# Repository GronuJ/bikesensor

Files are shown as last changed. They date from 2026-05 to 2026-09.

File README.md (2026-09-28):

# bikesensor 🚲📡

**A standalone, low-cost, pure IoT hardware and software mapping pipeline for geo-tagged bike vibration and road-quality analysis.**

`bikesensor` turns an ESP32-C3 SuperMini, an MPU-6050 IMU, a NEO-6M GPS, and an SPI MicroSD card module into a standalone, battery-powered mapping box. 

When you ride, the device autonomously records high-frequency (200 Hz) vertical accelerometer vibrations and sparse (1 Hz) GPS coordinate ticks into unified local CSV log files on the SD card. When you return home, the device connects to your home Wi-Fi and uploads all offline ride CSVs over HTTPS to [kiel.earth](https://kiel.earth), where the rides are stored, processed and mapped. That website lives in its own repository; this one holds the firmware, the carrier PCB and the enclosure.

---

## ⚠️ Project status

* **The custom PCB has been ordered** (38.74 × 114.47 mm, `production/bikesensor.zip`) but not assembled. Its ESP32 headers were routed against the wrong SuperMini pinout, so every signal lands on a different GPIO than the hand-wired prototype used. The default firmware build is remapped to match the board; the battery sense needs one bodge wire during assembly, and the module must be mounted face down. Details in `custom_pcb/PIN_VERIFICATION.md`.
* **The hardware has never produced a real ride.** Every figure produced so far comes from synthetic signals.

---

## 📸 Hardware Showcase

Below is the completed physical system mounted on a custom 3D-printed handlebar enclosure and its 3D modeling design:

| Physical System | 3D Printed Enclosure Design |
| :---: | :---: |
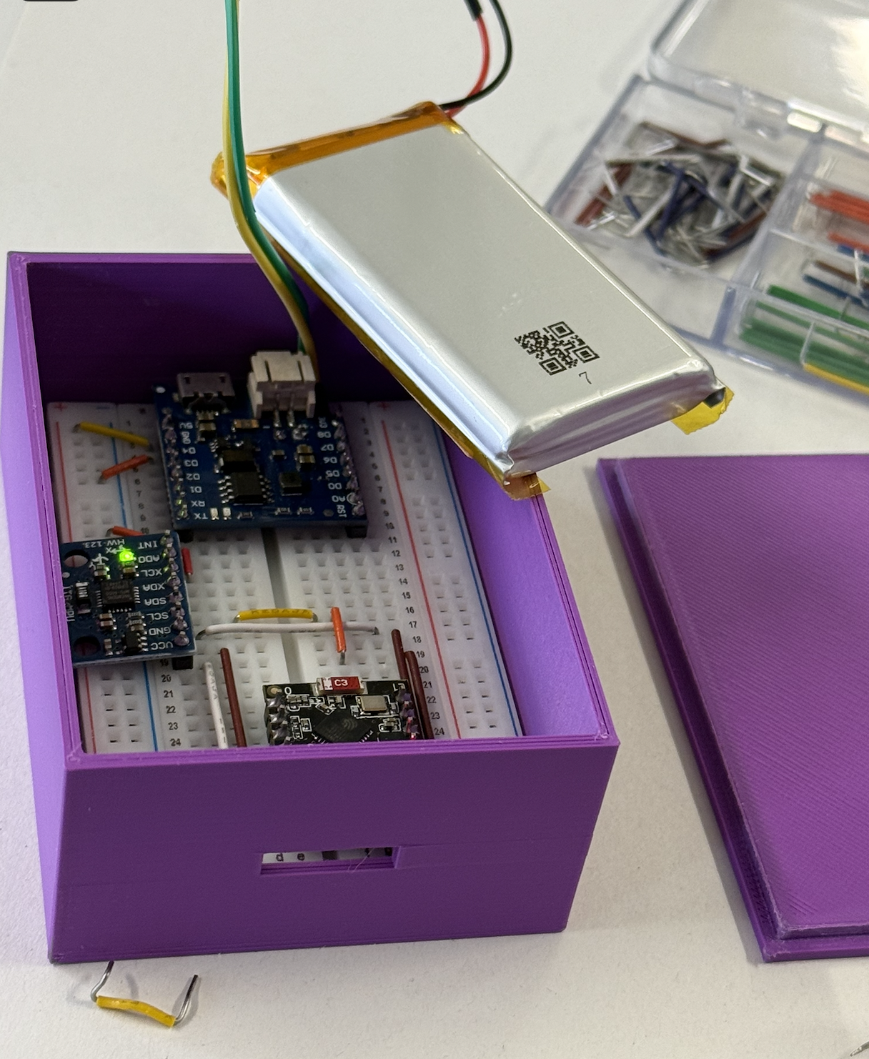
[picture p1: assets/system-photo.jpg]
Bikesensor Physical System
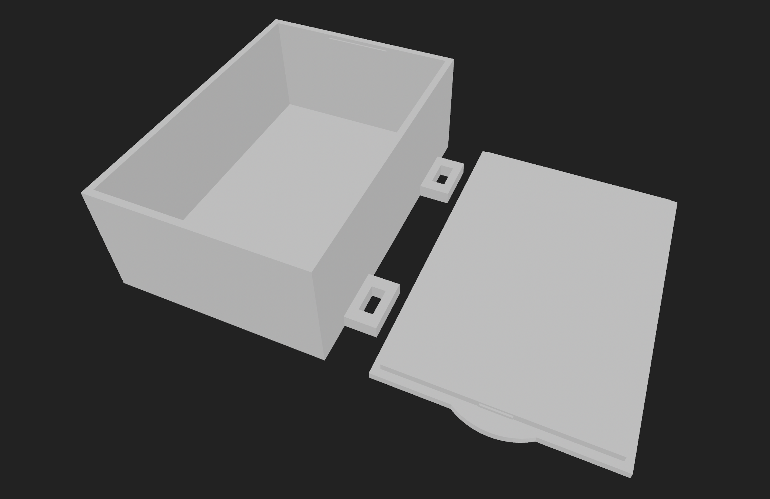
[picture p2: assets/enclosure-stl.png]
3D Printed Enclosure STL
|  |  |

---

## 1. System Architecture

```mermaid
flowchart TD
    subgraph Riding [1. Outdoor Bike Ride]
        ESP[ESP32-C3 SuperMini]
        IMU[MPU-6050 Accelerometer 200Hz] --> ESP
        GPS[NEO-6M GPS Module 1Hz] --> ESP
        ESP -->|Log unified CSV| SD[(SPI MicroSD Card)]
    end

    subgraph Home [2. Arrival Home & Wi-Fi Sync]
        ESP_H[ESP32-C3 Home Mode] -->|Connects to home Wi-Fi| Router((Home Router))
        SD -->|Stream CSVs over HTTPS POST| ESP_H
        ESP_H -->|/api/bike/ingest| Site[kiel.earth]
        Site -->|2xx: file is stored| ESP_H
        ESP_H -->|Delete uploaded file| SD
    end
```

---

## 2. Hardware Wiring & Custom PCB Carrier

The hardware operates on **3.3V logic** for standard communication and SD logging, driven by a Wemos D1 Mini TP5400 Battery Shield. 

Here is the physical wiring diagram for our custom carrier board:

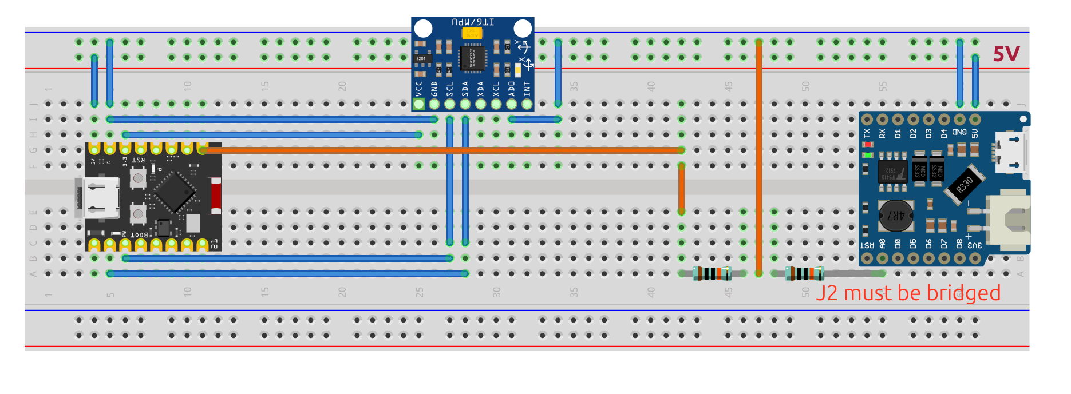
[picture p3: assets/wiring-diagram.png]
Bikesensor Electrical Wiring Diagram


### Schematic

R3 (10 kΩ) pulls `SPI_CS` to `+3V3`, keeping the card deselected while the ESP32 boots. The schematic's ESP32 connectors are generic sockets, so it does not show which GPIO each net reaches; the table below does.

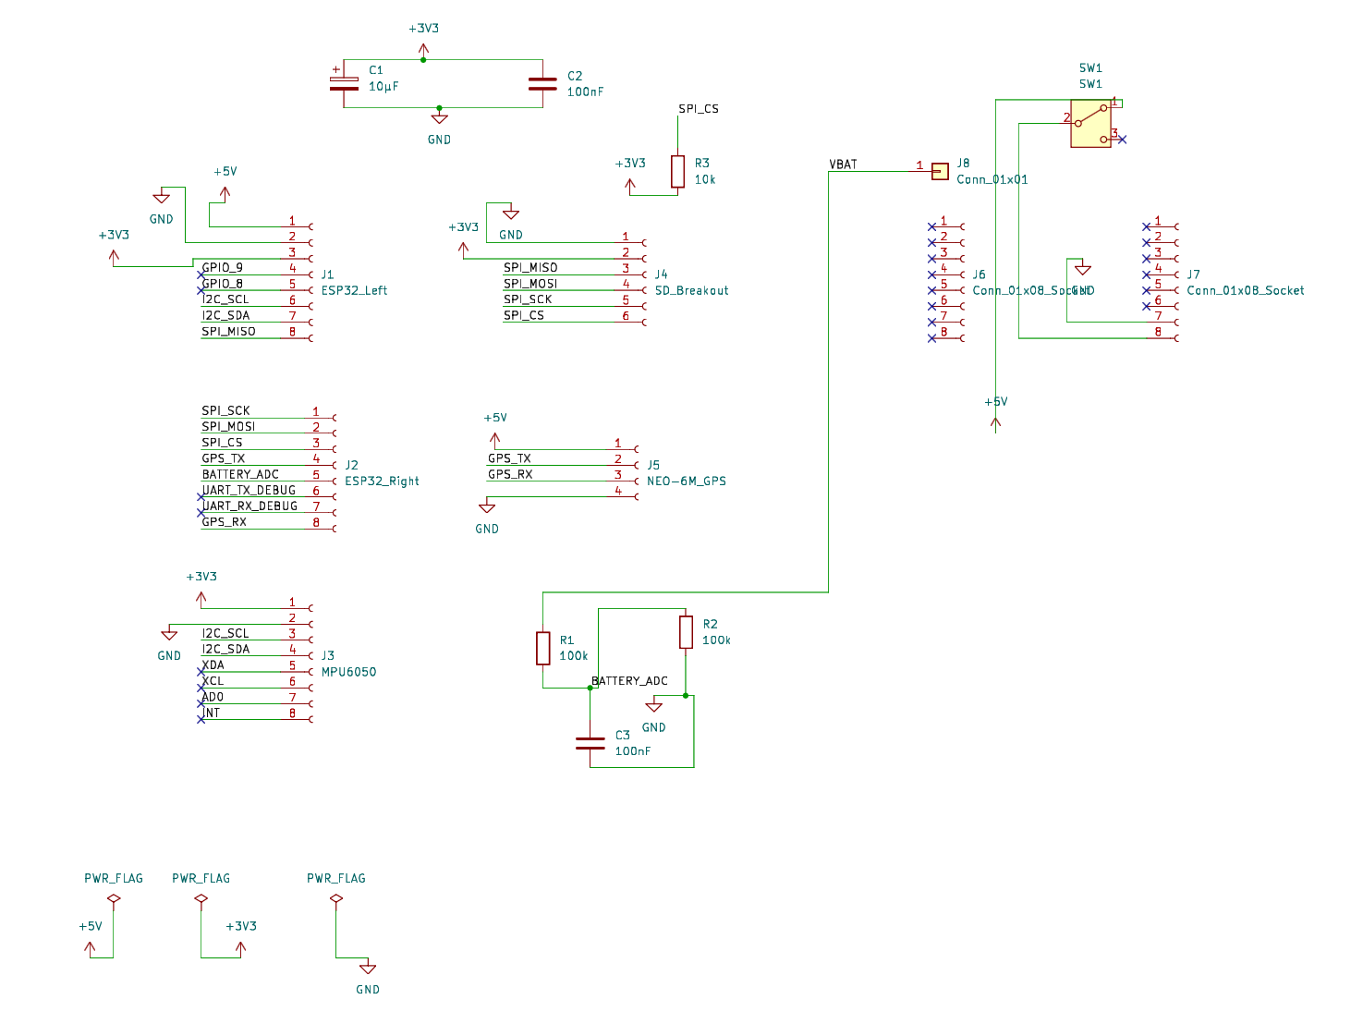
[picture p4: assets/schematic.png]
Schematic


### Board

The carrier is 38.74 × 114.47 mm, 2-layer, all through-hole. Every connected pin carries a silkscreen signal name — `GTX`/`GRX` are the GPS UART, `DTX`/`DRX` the debug UART, and `ADC` the battery divider.

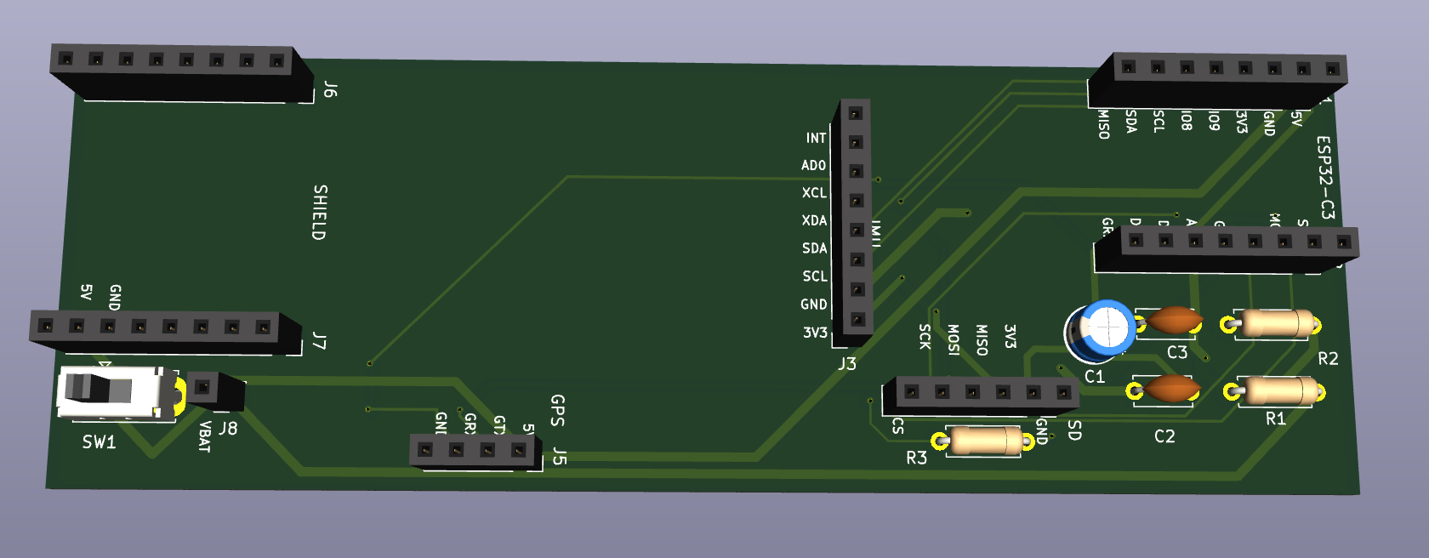
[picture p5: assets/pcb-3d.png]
PCB 3D render


### Pin Map Table:

GPIOs are for the carrier PCB (default firmware build). The hand-wired prototype used different ones — `pio run -d firmware -e handwired`.

| Peripheral | Connection | Pin | Notes |
| :--- | :--- | :--- | :--- |
| **MPU-6050 (I2C)** | SDA | **GPIO 1** | J1.7, shared I2C bus |
| | SCL | **GPIO 2** | J1.6. Strapping pin, held high by the GY-521's pull-ups |
| | VCC / GND | **3V3 / GND** | Powered by system 3.3V rail |
| **MicroSD (SPI)** | CS | **GPIO 7** | J2.3, R3 pull-up |
| | MOSI | **GPIO 6** | J2.2 |
| | SCK | **GPIO 5** | J2.1 |
| | MISO | **GPIO 0** | J1.8 |
| | VCC / GND | **3V3 / GND** | Powered by system 3.3V rail |
| **NEO-6M (UART1)** | TX / RX | **GPIO 8 / GPIO 21** | J2.4 / J2.8. Firmware detects which one the GPS transmits on |
| | VCC / GND | **5V / GND** | Powered by 5V boost output |
| **Wemos Battery Shield** | 5V Out | **J7 Pin 8** | Boosted 5.0V output |
| | GND | **J7 Pin 7** | System Ground |
| **SPDT Slide Switch (SW1)** | In / Out | **In Series** | Connected between `J7 Pin 8` (5V out) and `5V` net (ESP32 5V pin). Completely cuts off system power while preserving USB charging. |
| **Voltage Divider (R1, R2, C3)** | Junction | **GPIO 3** | Routed to J2.5 = GPIO 9, which has no ADC; reaches GPIO 3 only via the bodge wire in `PIN_VERIFICATION.md`. **R1 (100kΩ)** and **R2 (100kΩ)** divide raw battery voltage in half (`4.2V -> 2.1V`) for safe ADC reading. **C3 (100nF)** in parallel with R2 filters noise. |
| **Decoupling Caps (C1, C2)** | Parallel | **3V3 / GND** | **C1 (47µF radial; 10µF fits but is marginal)** and **C2 (100nF ceramic)** placed in parallel next to the MicroSD socket prevent write-cycle voltage sags. |

---

## 3. Firmwares (PlatformIO)

The firmware resides in `firmware/bikesensor/bikesensor.ino` and compiles out-of-the-box.

### Secure Credentials (Git-Ignored)
To protect your home Wi-Fi passwords from being committed to Git, create a file named `private_credentials.h` inside `firmware/bikesensor/`:
```cpp
#pragma once
#define WIFI_SSID "YourHomeSSID"
#define WIFI_PASS "YourHomePassword"
#define SERVER_HOST "kiel.earth"
#define SERVER_PORT 443
#define SERVER_UPLOAD_PATH "/api/bike/ingest"
#define DEVICE_TOKEN "your-device-token"   // sent as: Authorization: Bearer <token>
```
The firmware preprocessor will automatically detect and include this file during compile, keeping your passwords safe and isolated in your local workspace.

### Compilation Commands:
```bash
pio run -d firmware              # Build firmware binary
pio run -d firmware -t upload    # Flash to ESP32-C3 (Serial port is auto-detected)
pio device monitor -b 115200     # Real-time console debugger
```

---

## 4. Device-to-Server Interface

The logging box talks to the website over a single HTTPS endpoint.

### 4.1 CSV Log Data Format
When writing to the MicroSD card, the device registers data in a unified, comma-separated format:
```csv
millis,ax,ay,az,lat,lon,ele,speed_kmh,battery_pct,gps_time
```
*   `millis`: Relative milliseconds from ESP32 boot (used to align high-frequency vibration data).
*   `ax,ay,az`: Raw vertical/lateral/longitudinal accelerometer values (the ±4 g scale, `1/8192`, is applied on the website, not on the device).
*   `lat,lon,ele,speed_kmh`: GPS coordinate details.
*   `battery_pct`: Divided battery measurement (`0 - 100%`) read from `GPIO 3` on the carrier PCB (`GPIO 0` on the hand-wired prototype).
*   `gps_time`: GPS UTC timestamp (used as a clock reference).

### 4.2 Wireless Sync Protocol
When the ESP32-C3 boots in Wi-Fi sync mode upon returning home, it uploads every ride file on the SD card, one HTTPS request each:

*   **HTTP Method:** `POST`
*   **Request URL:** `https://kiel.earth/api/bike/ingest` (set by `SERVER_HOST` / `SERVER_UPLOAD_PATH`)
*   **Request Headers:** `Content-Type: text/csv`, `Authorization: Bearer <DEVICE_TOKEN>`, `X-Ride-Id: <filename without .csv>`
*   **Request Body:** the raw CSV file.

The device deletes a file from the SD card only after a 2xx response. On a timeout, TLS failure or any other status it keeps the file and retries on the next sync.

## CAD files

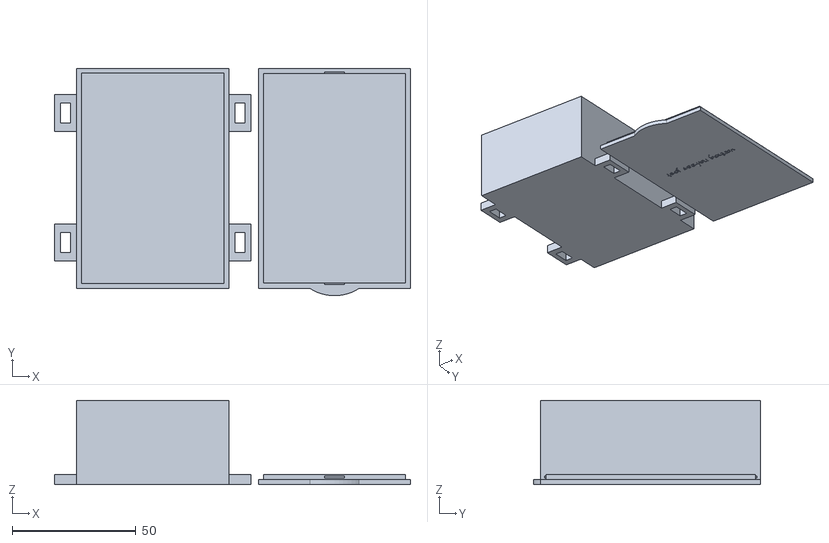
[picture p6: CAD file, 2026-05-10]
stl_files/box-3.stl
144.0 x 92.0 x 34.0

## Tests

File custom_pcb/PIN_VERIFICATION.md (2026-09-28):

# Pin verification sheet

Generated from `bikesensor_pcb/bikesensor_pcb.kicad_pcb` (the actual routed netlist), cross-referenced
against the real ESP32-C3 SuperMini pinout and the firmware constants in
`firmware/bikesensor/bikesensor.ino`.

**Why this file exists.** The schematic uses generic `Conn_01x0N_Socket` symbols — "ESP32_Left",
"MPU6050", "SD_Breakout" are only *Value* strings, not real parts with named pins. So the mapping
from header pin number to ESP32 GPIO exists nowhere the tools can check, and neither ERC nor DRC can
validate it. DRC passing clean means nothing here.

---

## Result (2026-09-22): J1/J2 were routed against the wrong pinout

The SuperMini's two rows, counted from the USB-C end, are:

```
row A:  5V   GND  3V3  IO4  IO3  IO2  IO1  IO0
row B:  IO5  IO6  IO7  IO8  IO9  IO10 IO20 IO21
```

Sources: the pad/pin tables in the [mrtnvgr/KiCad_ESP32-C3-SuperMini](https://github.com/mrtnvgr/KiCad_ESP32-C3-SuperMini)
footprint and symbol (pad 8 = 5V and pad 9 = IO5 share the same end, rows 15.24 mm apart), and the
[components101 pin table](https://components101.com/development-boards/esp32c3-mini-development-board-datasheet-pinout).
The same labels are printed on the module itself.

J1.1–J1.3 are `+5V, GND, +3V3`, so J1 is row A and J1.1 is the USB end. J2.1 sits directly across from
J1.1, so it is IO5. **This only works with the module face down** (see "Mount the module face down"
below): J1 is on the left of the carrier and J2 on the right, which is the mirror image of the module
seen from its component side. The board's `GPIO_9`/`GPIO_8` net names came from a pinout that
does not exist; the copper actually does this:

| Conn.pin | Net (silkscreen) | SuperMini pin | Hand-wired prototype used | Carrier firmware |
| --- | --- | --- | --- | --- |
| J1.1 | `+5V` | 5V | | |
| J1.2 | `GND` | GND | | |
| J1.3 | `+3V3` | 3V3 | | |
| J1.4 | `GPIO_9` (stub) | **IO4** | SPI SCK | free |
| J1.5 | `GPIO_8` (stub) | **IO3** | SPI MOSI | battery ADC, *after the bodge below* |
| J1.6 | `I2C_SCL` | **IO2** | SPI CS | I2C SCL |
| J1.7 | `I2C_SDA` | **IO1** | GPS (ESP TX) | I2C SDA |
| J1.8 | `SPI_MISO` | **IO0** | battery ADC | SPI MISO |
| J2.1 | `SPI_SCK` | **IO5** | SPI MISO | SPI SCK |
| J2.2 | `SPI_MOSI` | **IO6** | I2C SDA | SPI MOSI |
| J2.3 | `SPI_CS` | **IO7** | I2C SCL | SPI CS |
| J2.4 | `GPS_TX` | **IO8** (onboard LED) | LED | GPS UART, direction auto-detected |
| J2.5 | `BATTERY_ADC` | **IO9** (BOOT) | — | **none: IO9 has no ADC** |
| J2.6 | `UART_TX_DEBUG` | IO10 | GPS (ESP RX) | free |
| J2.7 | `UART_RX_DEBUG` | IO20 | | free |
| J2.8 | `GPS_RX` | IO21 | | GPS UART, direction auto-detected |

Not one signal lands where the original firmware expected it. The hand-wired prototype followed the
firmware, which is why it worked (the 2026-09-16 bench notes — divider on GPIO0, MISO on GPIO5, SDA
on GPIO6 — describe that hand wiring, not this PCB).

**What firmware absorbs.** The C3 routes SPI, I2C and UART through its GPIO matrix to any pin, so the
default firmware build (`pio run -d firmware`) now uses the "Carrier firmware" column. The original
map lives on as `pio run -d firmware -e handwired`. The GPS UART tries both carrier pins at boot and
uses whichever one carries NMEA, so the GPS breakout's header order (VCC-TX-RX-GND vs VCC-RX-TX-GND
both exist) does not matter.

**What firmware cannot absorb: the battery sense.** `BATTERY_ADC` lands on IO9, which has no ADC
channel, and IO9 is the BOOT strapping pin: it must read high at reset or the chip enters download
mode instead of running. With R1/R2 fitted, the divider (VBAT/2 through 50 kΩ) fights the ~45 kΩ
internal pull-up; that works out to about 2.5 V at a 3.3 V cell against a 2.48 V input-high threshold,
so a low battery could stop the logger booting.

### The one bodge (do it while assembling)

1. Before soldering J2, **clip off leg 5** of that 8-pin female header (or push its contact out). The
   module's IO9 then touches a contact that goes nowhere.
2. On the bottom side, solder a short wire from the **J2.5 pad** (still carrying `BATTERY_ADC` from
   R1/R2/C3) to the **J1.5 pad** (IO3, ADC1 channel 3; the `GPIO_8` stub has nothing else on it).

Result: battery sense on IO3, IO9 left to its internal pull-up and the BOOT button. The firmware's
carrier build already reads the battery on GPIO3.

If you would rather skip it: still clip leg 5, and leave R1 unfitted. The logger works;
`battery_pct` in the CSV is meaningless (IO3 floats).

### Mount the module face down

This is the standard assembly for this board revision, which is the one in use. J1/J2 are the
**mirror image** of the SuperMini seen face up (checked 2026-09-28 against the `.kicad_pcb` and the
fabricated board; the fab matches the design file). An earlier version of this file said either face
works; it does not.

The module goes in **face down**: chip, BOOT/RST buttons and USB-C toward the carrier, USB-C at the
board's top edge, the module's **5V pin in J1.1** (square pad, next to the `+5V`/`GND`/`3V3`
silkscreen). That is exactly the pin map in the table above and the carrier firmware's PIN MAP, so no
firmware change is needed.

Seen from its component side with USB-C at the top, the module is:

```
         [USB-C]
 IO5  o           o  5V
 IO6  o           o  GND
 IO7  o           o  3V3
 IO8  o           o  IO4
 IO9  o           o  IO3
 IO10 o           o  IO2
 IO20 o           o  IO1
 IO21 o           o  IO0
       [antenna]
```

Face down flips left and right, putting the 5V column over J1 on the left.

**Never power the module face up, in either rotation.** Both put a supply pin onto a signal net, which
risks the module and the breakouts; no firmware change can undo it:

| Pad | Carrier net (silkscreen) | Face down, USB at top (correct) | Face up, USB at top | Face up, USB at bottom |
| --- | --- | --- | --- | --- |
| J1.1 | `+5V` (5V) | 5V | IO5 ✗ | IO0 ✗ |
| J1.2 | `GND` (GND) | GND | IO6 ✗ | IO1 ✗ |
| J1.3 | `+3V3` (3V3) | 3V3 | IO7 ✗ | IO2 ✗ |
| J1.4 | `GPIO_9` (IO9) | IO4 (label wrong, unused) | IO8 | IO3 |
| J1.5 | `GPIO_8` (IO8) | IO3 (label wrong, bodge target) | IO9 | IO4 |
| J1.6 | `I2C_SCL` (SCL) | IO2 | IO10 | 3V3 ✗ |
| J1.7 | `I2C_SDA` (SDA) | IO1 | IO20 | GND ✗ |
| J1.8 | `SPI_MISO` (MISO) | IO0 | IO21 | 5V ✗ |
| J2.1 | `SPI_SCK` (SCK) | IO5 | 5V ✗ | IO21 |
| J2.2 | `SPI_MOSI` (MOSI) | IO6 | GND ✗ | IO20 |
| J2.3 | `SPI_CS` (CS) | IO7 | 3V3 ✗ | IO10 |
| J2.4 | `GPS_TX` (GTX) | IO8 | IO4 | IO9 |
| J2.5 | `BATTERY_ADC` (ADC) | IO9 (clip leg 5 + bodge) | IO3 | IO8 |
| J2.6 | `UART_TX_DEBUG` (DTX) | IO10 | IO2 | IO7 |
| J2.7 | `UART_RX_DEBUG` (DRX) | IO20 | IO1 | IO6 |
| J2.8 | `GPS_RX` (GRX) | IO21 | IO0 | IO5 |

✗ = a supply pin meets a signal net or another supply.

Jost confirmed on 2026-09-22 that the module he ordered (AliExpress "ESP32 C3 SuperMini Development
Board") has the pin order above; its printed labels (5V / G / 3.3 on one column, 21 and 0 at the
antenna end) match.

### Assembly notes

- **Solder the module's male header strips with the pins on the component side**: the black plastic
  spacer sits on the chip side and the pins stick out of it; solder on the plain back. Soldered the
  usual way (pins out of the back), the module cannot be seated correctly.
- **Clip J2 leg 5 and fit the J2.5 → J1.5 bodge wire** exactly as described above; face down is the
  orientation that bodge was written for.
- **BOOT and RST are unreachable while the module is seated.** Normal uploads over native USB do not
  need them. If a bad flash ever needs download mode, pull the module out of its sockets, hold BOOT
  while plugging in USB, and flash it off the board.
- **USB-C still reaches the board edge** and stays pluggable; the port sits a few millimetres lower and
  upside down, which USB-C does not care about. **Check the height of the enclosure's USB-C opening**
  before printing it.
- **Antenna:** it faces the carrier's bottom-layer ground pour, roughly 8–10 mm away (about 11 mm face
  up). Expect a small range loss; it only has to reach home Wi-Fi when parked.
- **Onboard LED and module labels are hidden.** The carrier firmware does not use the LED anyway.
- **Clearance:** nothing on the carrier sits under the module's footprint (C1, R2 and C3 are outside
  it).

A future respin with a real SuperMini footprint could let the module go face up again; none is planned.

### The other headers

All are single-row, so they cannot be mirrored the way J1/J2 are; the silkscreen only tells you which
way the breakout faces.

| Header | Pads 1→n (net) | Breakout's own order | Note |
| --- | --- | --- | --- |
| J3 IMU | 3V3, GND, SCL, SDA, XDA, XCL, AD0, INT | GY-521: VCC GND SCL SDA XDA XCL AD0 INT | Matches; VCC goes on the `3V3` end |
| J4 SD | GND, 3V3, MISO, MOSI, SCK, CS | Common 6-pin SD: GND VCC MISO MOSI SCK CS | Matches; see "Which MicroSD breakout?" below |
| J5 GPS | 5V, GTX, GRX, GND | GY-NEO6MV2: VCC RX TX GND | TX/RX order does not matter, firmware auto-detects |
| J6/J7 shield | J6 unconnected; J7.7 GND, J7.8 → SW1 (5V) | D1 mini: G and 5V are the last two of the TX row | **Inferred** to seat face up (J7 on the right, 5V at the bottom). Not checked against the actual shield: **confirm its G and 5V pins line up with J7.7/J7.8 before soldering** |

### Strapping pins at reset, as actually wired

| Pin | Needs at reset | On the carrier | OK? |
| --- | --- | --- | --- |
| IO2 | high | I2C SCL, pulled up by the GY-521's own pull-ups | yes |
| IO8 | high only for download mode | GPS UART line, idles high; onboard LED pulls it up too | yes |
| IO9 | high | internal pull-up + BOOT button, once leg 5 is clipped | yes, after the bodge |

---

## Cautions, re-evaluated against the real mapping

- **H2 — closed.** `SPI_CS` is on IO7, not the strapping pin GPIO2. Fit R3 anyway: it keeps the card
  deselected while the ESP32 boots.
- **H3 — accepted for this revision.** The R1/R2 divider still hangs off `/VBAT` upstream of SW1.
  Cost: ~21 µA permanent drain (years on any LiPo) and up to ~36 µA through R1 into the unpowered
  chip's pin clamp, far inside what the clamp tolerates. Move it downstream of SW1 in the respin.
  Leaving R1 unfitted removes it entirely.
- **H4 — fit a bigger C1.** Use 47 µF (≥ 6.3 V, 5 mm diameter, 2.0 mm lead pitch) instead of 10 µF. The
  3V3 rail comes from the SuperMini's LDO, rated for about 250 mA external load, and SD writes burst
  to 100–200 mA.
- **H5 — closed if the GPS is a GY-NEO6MV2.** That breakout has its own 3.3 V regulator (MIC5205), so
  its UART runs at 3.3 V even though it is fed 5 V. The 1 kΩ series resistors are optional. A bare
  NEO-6M or a 5 V-logic breakout would not be safe.
- **H6 — closed.** The GY-521 supplies the I2C pull-ups and pulls AD0 low (address 0x68); INT is unused.
  The `GPIO_8`/`GPIO_9` "stubs" are really IO3/IO4, not strapping pins. J6 is mechanical only.

### New, found in this pass

- **Which MicroSD breakout?** J4 feeds it `+3V3`. The common 6-pin module with an AMS1117 regulator and
  a 74LVC125 level shifter wants 5 V on VCC; at 3.3 V in, the card gets roughly 2.2–2.5 V and often
  fails to mount. If yours has a 3-pin SOT-223 regulator on it, bridge that regulator's input to its
  output, or feed J4.2 from `+5V` instead. A breakout without a regulator is fine as wired.
- **The onboard LED is gone.** GPIO8 is a GPS UART line on this board, so the carrier firmware never
  drives it. The LED will flicker once a second if the GPS happens to transmit on that pin.
- **Flash with SW1 off.** USB then powers the module and GPS through the module's 5V pin without
  back-feeding the battery shield's boost output.

---

## Bill of materials

Derived from the footprints in `bikesensor_pcb.kicad_pcb`, not from memory.

| Qty | Ref | Part | Footprint / note |
| --- | --- | --- | --- |
| 1 | — | ESP32-C3 SuperMini | seats across J1/J2 **face down**, rows 15.24 mm (600 mil) apart, **5V pin in J1.1**; header pins soldered on the component side |
| 1 | — | GY-521 (MPU-6050) | J3. **Supplies the I2C pull-ups** — the carrier has none |
| 1 | — | GY-NEO6MV2 GPS | J5. Must have its own regulator and 3.3 V logic; it is fed from 5 V with no level shifting |
| 1 | — | MicroSD SPI breakout | J4. Fed 3.3 V — see "Which MicroSD breakout?" above |
| 1 | — | Wemos D1 Mini TP5400 battery shield + LiPo | J6/J7/J8, rows 22.86 mm (900 mil) apart |
| 5 | J1 J2 J3 J6 J7 | 1x08 female header, 2.54 mm | **J2: clip leg 5** (the bodge). J6 is 8 electrically dead pins |
| 1 | J4 | 1x06 female header, 2.54 mm | |
| 1 | J5 | 1x04 female header, 2.54 mm | |
| 1 | J8 | 1x01 female header, 2.54 mm | VBAT sense |
| 2 | R1 R2 | 100 kΩ axial | `R_Axial_DIN0207`, 7.62 mm pitch |
| 1 | R3 | 10 kΩ axial | 7.62 mm pitch. CS pull-up |
| 1 | C1 | 47 µF electrolytic, ≥ 6.3 V | `CP_Radial_D5.0mm_P2.00mm`. 10 µF fits but is marginal — see **H4** |
| 2 | C2 C3 | 100 nF ceramic disc | `C_Disc_D5.0mm`, 5.00 mm pitch |
| 1 | SW1 | **C&K OS102011MS2Q** | See below — not a generic part |
| — | — | ~3 cm hookup wire | The J2.5 → J1.5 bodge |
| 2 | — | 1 kΩ axial *(optional)* | Series resistors on the GPS UART, **H5**. No footprint; fit inline on the wires |

**Use sockets, not direct soldering.** Being able to unseat the ESP32 is what allowed the prototype's
fault to be localised in software when no multimeter was available.

### SW1 is not substitutable

The footprint is **2.0 mm pitch**, three signal pins, with two mounting pegs 8.2 mm apart. A generic
2.54 mm slide switch **will not fit**. Buy the C&K part (or a pin-compatible C&K OS-series device)
from a distributor that carries C&K — Mouser, Digi-Key, Farnell or RS.

If you cannot get it, the board still works: solder a wire jumper between SW1 pads 1 and 2 to
hard-wire the 5 V rail on, or run flying leads to any SPDT switch off-board. You lose only the
power cut-off, not any function.

### PCB

2-layer, **38.74 x 114.47 mm**, 1.6 mm, HASL is fine — everything is through-hole with no fine
pitch. Note the board is longer than 100 mm, so it falls outside the cheapest fixed-price tier at
most prototype fabs. Upload `production/bikesensor.zip`.

---

## Before the respin

Replace the two generic sockets with a real SuperMini symbol and footprint (the mrtnvgr library above
has both), re-derive the netlist, and diff it against the firmware constants. Keeping the carrier
firmware map avoids re-routing most nets; the minimum respin change is moving `BATTERY_ADC` from
J2.5 (IO9) to J1.5 or J1.4 (IO3/IO4) and putting the divider downstream of SW1 (H3). Once the symbol
is real, this file becomes unnecessary, which is the point.

Closed on 2026-09-17: `+3V3` now reaches C1 pin 1, and R3 is in the design.

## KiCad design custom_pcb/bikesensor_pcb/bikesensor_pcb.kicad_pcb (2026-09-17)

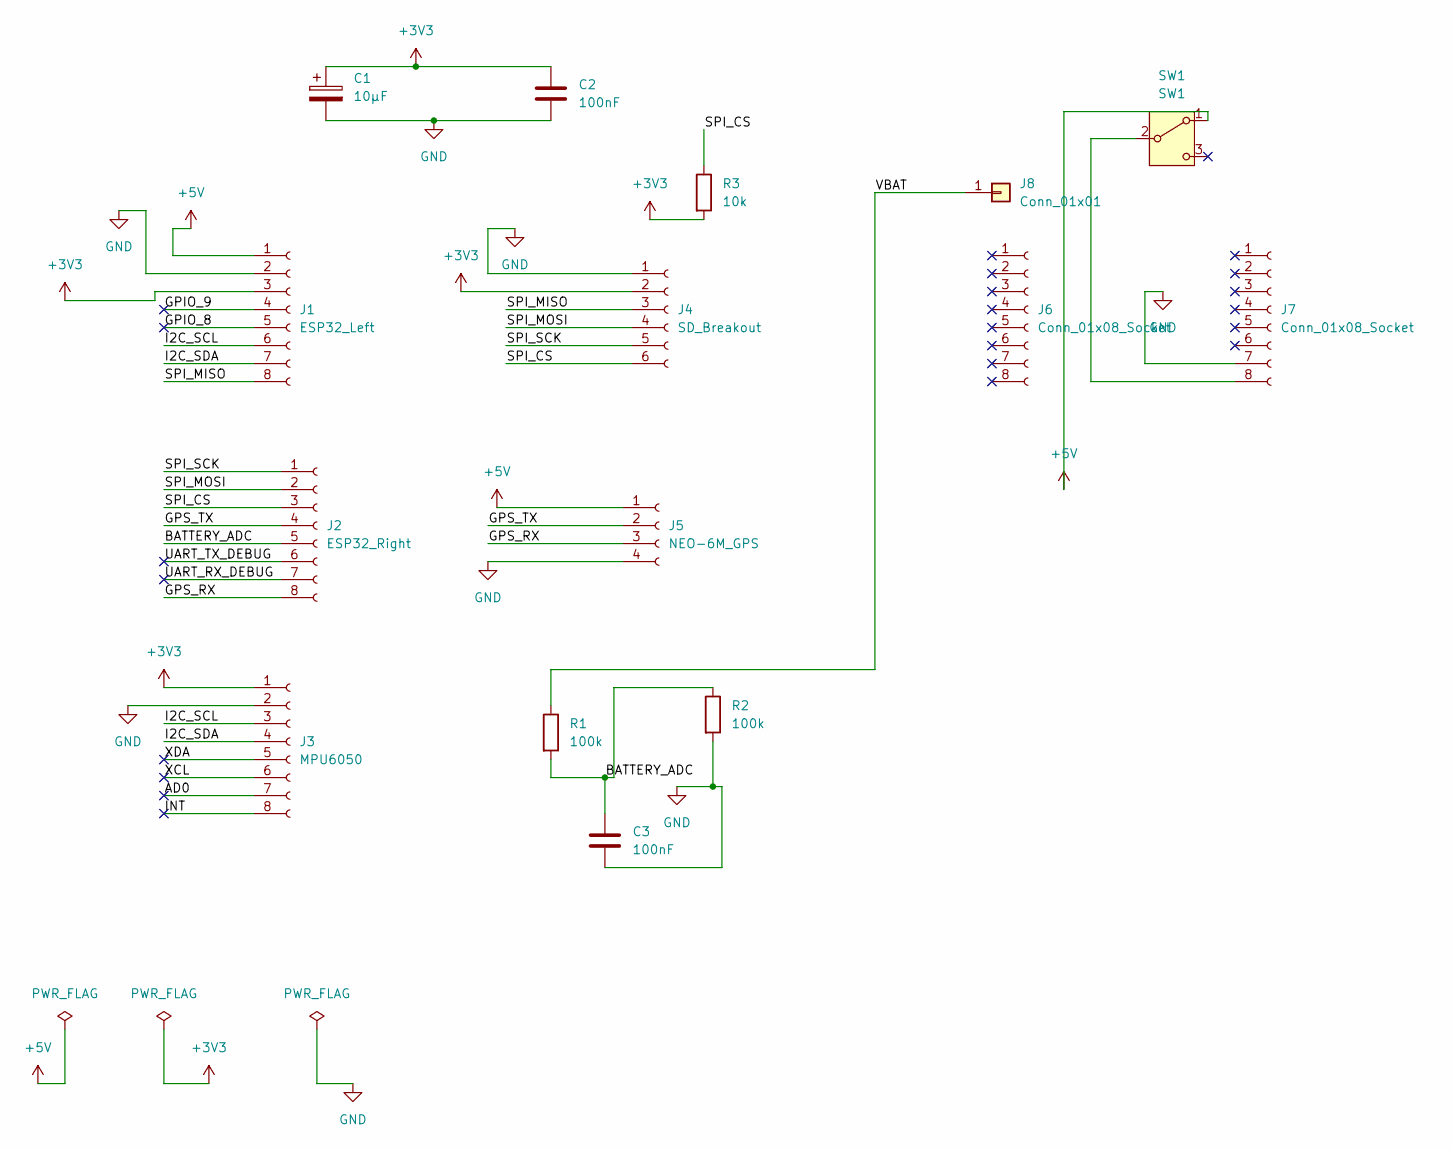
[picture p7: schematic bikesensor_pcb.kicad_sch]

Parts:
C1: 10µF; CP_Radial_D5.0mm_P2.00mm
C2, C3: 100nF; C_Disc_D5.0mm_W2.5mm_P5.00mm
J1: ESP32_Left; PinSocket_1x08_P2.54mm_Vertical
J2: ESP32_Right; PinSocket_1x08_P2.54mm_Vertical
J3: MPU6050; PinSocket_1x08_P2.54mm_Vertical
J4: SD_Breakout; PinSocket_1x06_P2.54mm_Vertical
J5: NEO-6M_GPS; PinSocket_1x04_P2.54mm_Vertical
J6, J7: Conn_01x08_Socket; PinSocket_1x08_P2.54mm_Vertical
J8: Conn_01x01; PinSocket_1x01_P2.54mm_Vertical
R1, R2: 100k; R_Axial_DIN0207_L6.3mm_D2.5mm_P7.62mm_Horizontal
R3: 10k; R_Axial_DIN0207_L6.3mm_D2.5mm_P7.62mm_Horizontal
SW1: SW1; SW_Slide_SPDT_Straight_CK_OS102011MS2Q

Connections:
+3V3: C1.1, C2.1, J1.3, J3.1, J4.2, R3.2
+5V: J1.1, J5.1, SW1.1 (A)
/AD0: J3.7
/BATTERY_ADC: C3.1, J2.5, R1.2, R2.1
/GPIO_8: J1.5
/GPIO_9: J1.4
/GPS_RX: J2.8, J5.3
/GPS_TX: J2.4, J5.2
/I2C_SCL: J1.6, J3.3
/I2C_SDA: J1.7, J3.4
/INT: J3.8
/SPI_CS: J2.3, J4.6, R3.1
/SPI_MISO: J1.8, J4.3
/SPI_MOSI: J2.2, J4.4
/SPI_SCK: J2.1, J4.5
/UART_RX_DEBUG: J2.7
/UART_TX_DEBUG: J2.6
/VBAT: J8.1 (Pin_1_1), R1.1
/XCL: J3.6
/XDA: J3.5
GND: C1.2, C2.2, C3.2, J1.2, J3.2, J4.1, J5.4, J7.7, R2.2
unnamed: J7.8, SW1.2 (B)

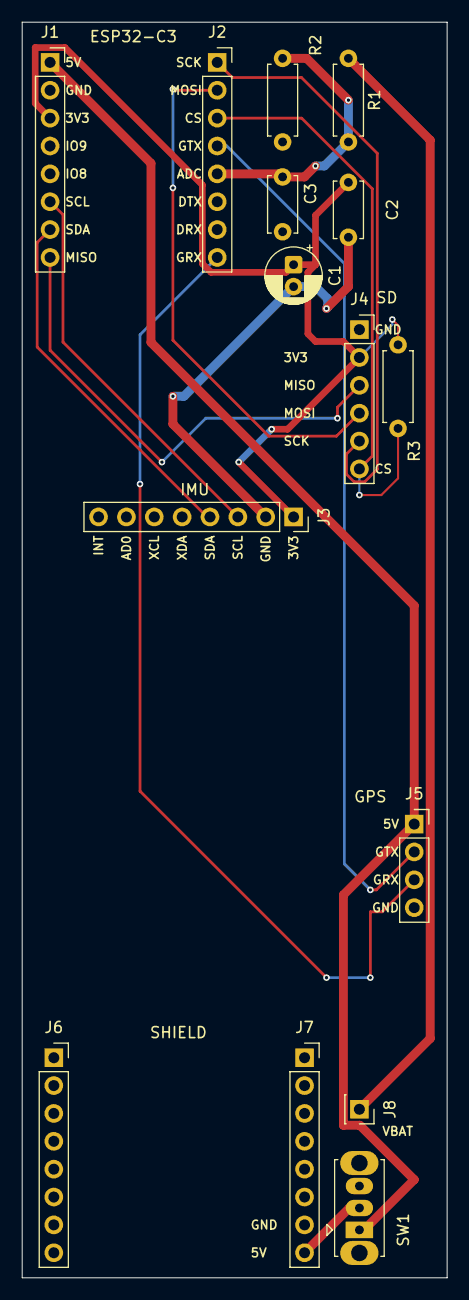
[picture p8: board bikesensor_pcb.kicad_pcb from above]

Board: 2 copper layers, 38.7 x 114.5 mm, 15 parts (0 on the bottom side), 14 nets.

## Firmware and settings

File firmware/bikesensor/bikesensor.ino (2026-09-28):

// ESP32-C3 Pure IoT Standalone Bike Mapping Logger & Wi-Fi Sync.
//
// Wiring (ESP32-C3 SuperMini) — two pin maps, see the PIN MAP block below:
//   Carrier PCB (default build, env esp32-c3-supermini):
//     MPU-6050 (I2C): SDA->GPIO 1, SCL->GPIO 2
//     MicroSD (SPI):  SCK->GPIO 5, MISO->GPIO 0, MOSI->GPIO 6, CS->GPIO 7
//     NEO-6M (GPS):   UART on GPIO 8 / GPIO 21, direction detected at boot
//     Battery:        GPIO 3, only after the J2.5 -> J1.5 bodge
//   Hand-wired prototype (env handwired):
//     MPU-6050 (I2C): SDA->GPIO 6, SCL->GPIO 7
//     MicroSD (SPI):  SCK->GPIO 4, MISO->GPIO 5, MOSI->GPIO 3, CS->GPIO 2
//     NEO-6M (GPS):   UART on GPIO 10 / GPIO 1, direction detected at boot
//     Battery:        GPIO 0
//
// Behaviour: at boot, and after every ride, it tries home Wi-Fi, uploads every
// ride file on the SD card and switches Wi-Fi off again. A ride starts when the
// bike has been moving for a few seconds and ends after three still minutes;
// nothing is written while the bike is parked.
//
// Build: PlatformIO (firmware/platformio.ini).

#include <Arduino.h>
#include <Wire.h>
#include <SPI.h>
#include <SD.h>
#include <WiFi.h>
#include <WiFiClientSecure.h>
#include <HTTPClient.h>

// Mozilla root bundle shipped with the Arduino-ESP32 core. Pinning a leaf
// certificate would break every 90 days when it rotates; the bundle does not.
extern const uint8_t rootca_crt_bundle_start[] asm("_binary_x509_crt_bundle_start");
#include <TinyGPS++.h>
#include <vector>

// ---------- CONFIGURATION ----------
#if __has_include("private_credentials.h")
#include "private_credentials.h"
#else
#define WIFI_SSID "YourHomeWiFi"        // Fallback SSID
#define WIFI_PASS "YourPassword"        // Fallback password
#define SERVER_HOST "kiel.earth"
#define SERVER_PORT 443
#define SERVER_UPLOAD_PATH "/api/bike/ingest"
#define DEVICE_TOKEN "set_me_in_private_credentials_h"
#endif

#ifndef SERVER_HOST
#define SERVER_HOST "kiel.earth"
#endif

#ifndef SERVER_PORT
#define SERVER_PORT 443
#endif

#ifndef SERVER_UPLOAD_PATH
#define SERVER_UPLOAD_PATH "/api/bike/ingest"
#endif

#ifndef DEVICE_TOKEN
#define DEVICE_TOKEN "set_me_in_private_credentials_h"
#endif

// ---------- PIN MAP ----------
// The carrier PCB's J1/J2 were routed against a SuperMini pinout that does not
// exist, so every signal lands on a different GPIO than the hand-wired prototype
// used. The C3's GPIO matrix lets SPI, I2C and UART sit on any pin, so the
// firmware absorbs it; only the battery ADC needed a bodge.
// See custom_pcb/PIN_VERIFICATION.md.
#ifdef BIKESENSOR_HANDWIRED
static constexpr uint8_t PIN_SPI_SCK  = 4;
static constexpr uint8_t PIN_SPI_MISO = 5;
static constexpr uint8_t PIN_SPI_MOSI = 3;
static constexpr uint8_t PIN_SPI_CS   = 2;
static constexpr uint8_t PIN_I2C_SDA  = 6;
static constexpr uint8_t PIN_I2C_SCL  = 7;
// The two pins wired to the GPS UART. Which one carries the GPS's TX is
// detected at boot, since breakouts ship with either header order.
static constexpr uint8_t PIN_GPS_A    = 10;
static constexpr uint8_t PIN_GPS_B    = 1;
static constexpr uint8_t PIN_BATTERY  = 0;
static constexpr int8_t  PIN_LED      = 8;  // onboard blue LED, active-low
#else
static constexpr uint8_t PIN_SPI_SCK  = 5;  // J2.1
static constexpr uint8_t PIN_SPI_MISO = 0;  // J1.8
static constexpr uint8_t PIN_SPI_MOSI = 6;  // J2.2
static constexpr uint8_t PIN_SPI_CS   = 7;  // J2.3, R3 pull-up
static constexpr uint8_t PIN_I2C_SDA  = 1;  // J1.7
static constexpr uint8_t PIN_I2C_SCL  = 2;  // J1.6
static constexpr uint8_t PIN_GPS_A    = 21; // J2.8 -> J5.3
static constexpr uint8_t PIN_GPS_B    = 8;  // J2.4 -> J5.2
// BATTERY_ADC is routed to J2.5 = GPIO9, which has no ADC. Readings are only
// real after the bodge wire moves the divider to J1.5 = GPIO3.
static constexpr uint8_t PIN_BATTERY  = 3;
static constexpr int8_t  PIN_LED      = -1; // GPIO8 carries the GPS UART here
#endif

// MPU-6050 I2C Address
static constexpr uint8_t MPU_ADDR = 0x68;

// Logging Parameters
// 200 Hz, not 100. Cobblestone excites the frame at (speed / sett pitch): 10cm
// setts at 15 km/h is 42 Hz, at 20 km/h 56 Hz. At 100 Hz sampling the Nyquist
// limit is 50 Hz, so the most common German Kleinpflaster aliases away at normal
// riding speed and no amount of processing recovers it. 200 Hz moves the limit
// to 100 Hz and covers setts down to ~6 cm.
static constexpr uint16_t SAMPLE_RATE_HZ = 200;
static constexpr uint32_t SAMPLE_INTERVAL_US = 1000000UL / SAMPLE_RATE_HZ;

static const char CSV_HEADER[] = "millis,ax,ay,az,lat,lon,ele,speed_kmh,battery_pct,gps_time";

// Ride detection. A ride starts after MOVE_START_S consecutive moving seconds
// and ends after STILL_END_S consecutive still seconds; rides with fewer than
// MIN_RIDE_MOVING_S moving seconds (wheeling the bike out of the hallway) are
// deleted instead of uploaded. A second counts as moving when the accelerometer
// is busy or the GPS says we are rolling.
//
// MOTION_THRESHOLD is PROVISIONAL, reasoned rather than measured: the metric is
// the mean |sample-to-sample change| summed over the three axes, in raw counts.
// MPU-6050 noise at the 94 Hz DLPF is ~4 mg rms per axis, which gives ~110 at
// rest; smooth asphalt at 0.02 g rms gives several hundred. The serial console
// prints the metric every 5 s — calibrate from a real ride.
static constexpr uint32_t MOTION_THRESHOLD   = 300;
static constexpr float    GPS_MOVING_KMH     = 8.0;
static constexpr float    GPS_STILL_KMH      = 3.0;
static constexpr uint16_t MOVE_START_S       = 3;
static constexpr uint16_t STILL_END_S        = 180;  // longer than any red light
static constexpr uint16_t MIN_RIDE_MOVING_S  = 60;

// A position older than this is not written. TinyGPS++ keeps location.isValid()
// true forever after the first fix and keeps committing the time without one, so
// without an age check a lost fix repeats the last position with fresh times.
static constexpr uint32_t FIX_MAX_AGE_MS = 1500;

// The battery shield's divider halves the cell voltage. A reading outside
// BATTERY_MIN_V..BATTERY_MAX_V is not a Li-ion cell — typically the carrier
// without its GPIO9 -> GPIO3 bodge, where the ADC pin floats — so the column is
// left empty rather than filled with a made-up percentage.
static constexpr float BATTERY_DIVIDER = 2.0;
static constexpr float BATTERY_MIN_V   = 2.8;
static constexpr float BATTERY_MAX_V   = 4.5;

// State Variables
File logFile;
char currentRideFilename[32];
bool isLoggingActive = false;
static bool sdReady = false;
static bool imuReady = false;

// GPS Object
TinyGPSPlus gps;
HardwareSerial GPSSerial(1); // Use hardware UART1

// ---------- STATUS LED ----------
static void ledSet(bool on) {
  if (PIN_LED >= 0) digitalWrite(PIN_LED, on ? LOW : HIGH); // active-low
}

// ---------- GPS UART ----------
// Listens on one pin with TX left unassigned, so nothing drives a line the GPS
// may itself be driving. The NEO-6M emits sentences every second, fix or not.
static bool gpsTalksOn(uint8_t rxPin, uint32_t baud) {
  static const char kTalker[] = "$GP";
  GPSSerial.begin(baud, SERIAL_8N1, rxPin, -1);
  uint8_t matched = 0;
  bool found = false;
  uint32_t t0 = millis();
  while (!found && millis() - t0 < 1500) {
    while (GPSSerial.available() > 0) {
      char c = GPSSerial.read();
      matched = (c == kTalker[matched]) ? matched + 1 : (c == '$' ? 1 : 0);
      if (matched == 3) { found = true; break; }
    }
    delay(5);
  }
  GPSSerial.end();
  return found;
}

static void gpsBegin() {
  const uint8_t pins[2] = {PIN_GPS_A, PIN_GPS_B};
  // 115200 is what the module was configured to on the prototype; 9600 is the
  // NEO-6M factory default, in case that setting was never saved.
  const uint32_t bauds[2] = {115200, 9600};
  for (uint32_t baud : bauds) {
    for (int i = 0; i < 2; i++) {
      if (gpsTalksOn(pins[i], baud)) {
        GPSSerial.begin(baud, SERIAL_8N1, pins[i], pins[1 - i]);
        Serial.printf("NEO-6M found: GPS TX on GPIO %u, %lu baud.\n", pins[i], (unsigned long)baud);
        return;
      }
    }
  }
  Serial.println("⚠ No NMEA on either GPS pin. Check J5 and GPS power; assuming the default order.");
  GPSSerial.begin(bauds[0], SERIAL_8N1, pins[0], pins[1]);
}

// ---------- BATTERY MEASUREMENT ----------
// Returns -1 when the reading is not plausibly a cell (see BATTERY_MIN_V).
static int getBatteryPercent() {
  uint32_t mv = 0;
  for (int i = 0; i < 8; i++) mv += analogReadMilliVolts(PIN_BATTERY);
  float voltage = (mv / 8.0) * BATTERY_DIVIDER / 1000.0;
  if (voltage < BATTERY_MIN_V || voltage > BATTERY_MAX_V) return -1;
  if (voltage >= 4.2) return 100;
  if (voltage <= 3.3) return 0;
  return (int)(((voltage - 3.3) / (4.2 - 3.3)) * 100.0);
}

// ---------- MPU-6050 ACCEL ONLY ----------
static void w8(uint8_t reg, uint8_t v) {
  Wire.beginTransmission(MPU_ADDR);
  Wire.write(reg); Wire.write(v);
  Wire.endTransmission();
}

// Probes and configures the IMU. Called at boot and again whenever it has gone
// missing, so a loose header costs a gap in the data rather than the ride.
static bool mpuInit() {
  Wire.beginTransmission(MPU_ADDR);
  if (Wire.endTransmission() != 0) return false;
  w8(0x6B, 0x80); delay(100); // Reset MPU-6050
  w8(0x6B, 0x01);             // Clock source PLL with X gyro
  w8(0x1A, 0x02);             // DLPF CONFIG: Accel BW = 94Hz — the anti-alias filter
                              // must sit just under Nyquist (100Hz at 200Hz sampling).
                              // Leaving this at 44Hz would throw away exactly the band
                              // that cobblestone lives in.
  w8(0x1C, 0x08);             // ACCEL_CONFIG: Full scale range ±4 g
  Serial.println("MPU-6050 initialized.");
  return true;
}

// False when the IMU did not answer; the caller must not use ax/ay/az then.
static bool readAccel(int16_t &ax, int16_t &ay, int16_t &az) {
  Wire.beginTransmission(MPU_ADDR);
  Wire.write(0x3B); // Accel data register 59
  if (Wire.endTransmission(false) != 0) return false;
  if (Wire.requestFrom((int)MPU_ADDR, 6) != 6 || Wire.available() < 6) return false;
  ax = (Wire.read() << 8) | Wire.read();
  ay = (Wire.read() << 8) | Wire.read();
  az = (Wire.read() << 8) | Wire.read();
  return true;
}

// ---------- MICROSD ----------
static bool mountSd() {
  if (!SD.begin(PIN_SPI_CS)) return false;
  Serial.println("MicroSD card mounted successfully.");
  return true;
}

static String getServerUrl() {
  return String("https://") + SERVER_HOST + SERVER_UPLOAD_PATH;
}

// The ride id is the SD filename without its extension, fixed when the file is
// created. Because it lives in the filename it is stable across reboots — so if
// an upload response is lost, the retry carries the same id and the server
// recognises the replay instead of storing the ride twice. Rides start on
// motion, usually after the GPS has its clock, so the name is normally the start
// time; without a GPS clock it falls back to a hardware random.
static void makeRideFilename(char *out, size_t n) {
  if (gps.date.isValid() && gps.time.isValid() && gps.date.year() > 2020) {
    snprintf(out, n, "/r%02d%02d%02d_%02d%02d%02d.csv",
             gps.date.year() % 100, gps.date.month(), gps.date.day(),
             gps.time.hour(), gps.time.minute(), gps.time.second());
  } else {
    snprintf(out, n, "/rboot_%08lx.csv", (unsigned long)esp_random());
  }
}

static String rideIdFromFilename(const String &filename) {
  String id = filename;
  if (id.startsWith("/")) id = id.substring(1);
  int dot = id.lastIndexOf('.');
  if (dot > 0) id = id.substring(0, dot);
  return id;
}
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
void loop() {
  uint32_t now = millis();
  uint32_t nowUs = micros();

  // 1. Process the incoming NMEA stream from the GPS module continuously
  while (GPSSerial.available() > 0) {
    gps.encode(GPSSerial.read());
  }

  // 2. Latch once per GPS clock second. The time keeps ticking without a fix, so
  // the row still carries the battery and gps_time; the position fields are
  // written only when the fix is current.
  if (gps.time.isValid()) {
    uint32_t currentGpsTimeVal = gps.time.value(); // Format: HHMMSSCC
    if (currentGpsTimeVal != lastGpsTimeVal) {
      lastGpsTimeVal = currentGpsTimeVal;
      newGpsDataAvailable = true;
      lastFixFresh = gps.location.isValid() && gps.location.age() < FIX_MAX_AGE_MS;
      lastLat = gps.location.lat();
      lastLon = gps.location.lng();
      lastEle = gps.altitude.meters();
      lastSpeed = gps.speed.kmph();
      if (gps.date.isValid() && gps.date.year() > 2020) {
        snprintf(lastGpsTime, sizeof(lastGpsTime), "%04d-%02d-%02dT%02d:%02d:%02dZ",
                 gps.date.year(), gps.date.month(), gps.date.day(),
                 gps.time.hour(), gps.time.minute(), gps.time.second());
      } else {
        lastGpsTime[0] = '\0';
      }
    }
  }

  // 3. Missing hardware is retried rather than fatal.
  static uint32_t lastSdRetryMs = 0;
  if (!sdReady && now - lastSdRetryMs > 5000) {
    lastSdRetryMs = now;
    SD.end();
    sdReady = mountSd();
  }
  static uint32_t lastImuRetryMs = 0;
  if (!imuReady && now - lastImuRetryMs > 1000) {
    lastImuRetryMs = now;
    imuReady = mpuInit();
  }

  // 4. Strict SAMPLE_RATE_HZ sampling, scheduled in microseconds so millis()'s
  // 1 ms steps do not add jitter. A late sample is caught up only if it is less
  // than half a period late. Anything later resyncs the phase, which turns a
  // stall into a clean gap in the millis column that the DSP splits on, instead
  // of two samples bunched a millisecond or two apart that it cannot detect.
  static uint32_t nextSampleUs = 0;
  static bool scheduled = false;
  if (!scheduled) { nextSampleUs = nowUs; scheduled = true; }

  // Ride detection accumulators, evaluated once a second.
  static uint32_t motionSum = 0, motionCount = 0;
  static int16_t pax = 0, pay = 0, paz = 0;
  static bool havePrev = false;
  static uint32_t lastMotionMetric = 0;
  static uint16_t movingStreak = 0, stillStreak = 0;
  static uint32_t rideMovingSeconds = 0;
  static uint32_t imuFailStreak = 0;
  static uint32_t writeFailStreak = 0;

  if ((int32_t)(nowUs - nextSampleUs) >= 0) {
    if (nowUs - nextSampleUs > SAMPLE_INTERVAL_US / 2) {
      nextSampleUs = nowUs + SAMPLE_INTERVAL_US;
    } else {
      nextSampleUs += SAMPLE_INTERVAL_US;
    }

    int16_t ax = 0, ay = 0, az = 0;
    bool accelOk = imuReady && readAccel(ax, ay, az);
    if (accelOk) {
      imuFailStreak = 0;
      if (havePrev) {
        motionSum += abs(ax - pax) + abs(ay - pay) + abs(az - paz);
        motionCount++;
      }
      pax = ax; pay = ay; paz = az; havePrev = true;
    } else if (imuReady && ++imuFailStreak >= SAMPLE_RATE_HZ) {
      // A whole second of failed reads: treat the IMU as gone and re-probe it.
      Serial.println("❌ MPU-6050 stopped answering; re-probing every second.");
      imuReady = false;
      havePrev = false;
    }

    if (isLoggingActive &&
        (accelOk || (newGpsDataAvailable && (lastFixFresh || lastGpsTime[0])))) {
      // A failed accelerometer read writes no 200 Hz row (a gap the DSP splits
      // on), but a GPS-second row is still written with ax/ay/az left empty.
      char row[160];
      int n = snprintf(row, sizeof(row), "%lu,", (unsigned long)now);
      if (accelOk) n += snprintf(row + n, sizeof(row) - n, "%d,%d,%d", ax, ay, az);
      else         n += snprintf(row + n, sizeof(row) - n, ",,");
      if (newGpsDataAvailable) {
        int batt = getBatteryPercent();
        char battStr[8] = "";
        if (batt >= 0) snprintf(battStr, sizeof(battStr), "%d", batt);
        if (lastFixFresh) {
          n += snprintf(row + n, sizeof(row) - n, ",%.6f,%.6f,%.1f,%.2f,%s,%s\n",
                        lastLat, lastLon, lastEle, lastSpeed, battStr, lastGpsTime);
        } else {
          n += snprintf(row + n, sizeof(row) - n, ",,,,,%s,%s\n", battStr, lastGpsTime);
        }
      } else {
        n += snprintf(row + n, sizeof(row) - n, ",,,,,,\n");
      }
      if (logFile.write((const uint8_t *)row, n) == (size_t)n) {
        writeFailStreak = 0;
      } else if (++writeFailStreak >= SAMPLE_RATE_HZ) {
        // A second of failed writes: the card is gone. Keep what was written.
        Serial.println("❌ Writes to the SD card are failing; ending the ride and remounting.");
        logFile.close();
        isLoggingActive = false;
        sdReady = false;
        writeFailStreak = 0;
      }
    }
    newGpsDataAvailable = false;

    // Put what is written on the card every 5 s. flush() writes the buffer and
    // syncs the FAT size (fsync), so a power cut loses at most 5 s. It replaces a
    // close/reopen, which also rewrote the directory entry and took longer.
    static uint32_t lastFlushMs = 0;
    if (isLoggingActive && now - lastFlushMs > 5000) {
      logFile.flush();
      lastFlushMs = now;
    }
  }

  // 5. Once a second: is the bike moving? Start or end the ride.
  static uint32_t lastMotionEvalMs = 0;
  if (now - lastMotionEvalMs >= 1000) {
    lastMotionEvalMs = now;
    lastMotionMetric = motionCount ? motionSum / motionCount : 0;
    motionSum = 0; motionCount = 0;

    bool gpsFresh = gps.location.isValid() && gps.location.age() < FIX_MAX_AGE_MS &&
                    gps.speed.isValid() && gps.speed.age() < FIX_MAX_AGE_MS;
    float speed = gpsFresh ? gps.speed.kmph() : 0.0;
    bool moving = lastMotionMetric > MOTION_THRESHOLD || speed >= GPS_MOVING_KMH;
    bool still  = lastMotionMetric <= MOTION_THRESHOLD && speed < GPS_STILL_KMH;

    if (!isLoggingActive) {
      movingStreak = moving ? movingStreak + 1 : 0;
      if (movingStreak >= MOVE_START_S && sdReady) {
        movingStreak = 0; stillStreak = 0; rideMovingSeconds = 0;
        startNewRideLogging();
      }
    } else {
      if (moving) rideMovingSeconds++;
      stillStreak = still ? stillStreak + 1 : 0;
      if (stillStreak >= STILL_END_S) {
        stillStreak = 0;
        endRideLogging(rideMovingSeconds);
        // Parked: if this is home, upload now rather than at the next power-on.
        attemptWiFiSync();
        nextSampleUs = micros();
        havePrev = false;
        lastMotionEvalMs = millis();
      }
    }
  }

  // 6. Periodic diagnostic print (every 5 seconds) to Serial console
  static uint32_t lastDiagPrintMs = 0;
  if (now - lastDiagPrintMs > 5000) {
    lastDiagPrintMs = now;
    // -1 means "not a plausible cell" (no battery, or no bodge wire): the CSV
    // leaves the field empty, so the console says so instead of printing -1%.
    int batt = getBatteryPercent();
    char battStr[16] = "no battery";
    if (batt >= 0) snprintf(battStr, sizeof(battStr), "%d%%", batt);
    Serial.printf("[DIAGNOSTIC] %s | motion %lu (threshold %lu) | GPS %s | battery ADC %d mV = %s | SD %s | IMU %s\n",
                  isLoggingActive ? "RIDING" : "idle",
                  (unsigned long)lastMotionMetric, (unsigned long)MOTION_THRESHOLD,
                  gps.location.isValid() && gps.location.age() < FIX_MAX_AGE_MS ? "fix" : "no fix",
                  analogReadMilliVolts(PIN_BATTERY), battStr,
                  sdReady ? "ok" : "MISSING", imuReady ? "ok" : "MISSING");
  }

  // 7. Onboard LED (prototype only; the carrier has none): fast blink while the
  // SD card or IMU is missing, a short pulse every 2 s while recording.
  static uint32_t lastLEDMs = 0;
  static bool ledOn = false;
  if (!sdReady || !imuReady) {
    if (now - lastLEDMs > 100) { ledOn = !ledOn; ledSet(ledOn); lastLEDMs = now; }
  } else if (isLoggingActive) {
    if (!ledOn && now - lastLEDMs > 2000) { ledSet(true); ledOn = true; lastLEDMs = now; }
    else if (ledOn && now - lastLEDMs > 15) { ledSet(false); ledOn = false; }
  } else if (ledOn) {
    ledSet(false); ledOn = false;
  }

  delay(1); // keeps loop snappy
}

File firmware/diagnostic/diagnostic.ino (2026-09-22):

// SD card check now that the GPIO6 short is gone.
#include <Arduino.h>
#include <SPI.h>
#include <SD.h>

static void tryMount(uint8_t sck, uint8_t miso, uint8_t mosi, uint8_t cs, uint32_t hz){
  SPI.end(); delay(20);
  SPI.begin(sck, miso, mosi, cs);
  if (SD.begin(cs, SPI, hz)) {
    Serial.printf("  MOUNTED  SCK=%u MISO=%u MOSI=%u CS=%u @%lukHz  size=%llu MB\n",
                  sck, miso, mosi, cs, (unsigned long)(hz/1000), SD.cardSize() >> 20);
    File f = SD.open("/probe.txt", FILE_WRITE);
    if (f) { f.println("bikesensor"); f.close();
             Serial.println("    write OK"); SD.remove("/probe.txt"); }
    else Serial.println("    mounted but write FAILED");
    SD.end();
  } else {
    Serial.printf("  failed   SCK=%u MISO=%u MOSI=%u CS=%u @%lukHz\n", sck, miso, mosi, cs, (unsigned long)(hz/1000));
  }
}

void setup(){ Serial.begin(115200); delay(1500); }

void loop(){
  Serial.println("\n\n#### SD CHECK ####");
  Serial.println("Cheap modules and long hand-wiring often need a slower clock.\n");
  // Carrier PCB: SCK=5 MISO=0 MOSI=6 CS=7. The hand-wired prototype used 4,5,3,2.
  tryMount(5,0,6,7, 400000);
  tryMount(5,0,6,7, 1000000);
  tryMount(5,0,6,7, 4000000);
  Serial.println("\n#### END ####");
  delay(12000);
}

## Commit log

2026-05-08 initial bikesensor pipeline: lightblue parse, gpx+imu merge, streamlit dashboard
2026-05-08 firmware + pipeline rewrite for ~2m FFT mapping
    - ESP32/MPU-6050 NimBLE firmware: 250Hz FIFO, batched packets, sync packets for clock model
    - lightblue_parse: decode SYNC/DATA packets, fit linear clock model from SYNCs
    - analysis: STFT band-energy features (0.5s win, 0.1s hop)
    - merge: interpolate GPX onto window centers for sub-meter along-track localization
    - dashboard: folium heatmap, click-to-spectrum, plotly along-route plots
2026-05-08 target esp32-c3 supermini: usb-cdc, i2c on gpio 6/7, serial heartbeat
2026-05-09 update BLE device name to bikesensor_vanhoge
2026-05-09 update BLE device name to bikesensor_vanhog
2026-05-09 feat: add streamlit file uploader and rename BLE device to bikesensor_jj
2026-05-10 feat: add max_bump_g metric and redesign dashboard layout
    - Add 25Hz Butterworth low-pass filter to extract max_bump_g (physical bump severity)
    - Redesign dashboard using tabs and columns for a professional layout
    - Add time-domain plot with filtered bump signal to local analysis
    - Set max_bump_g as the default map metric
2026-05-10 feat: transmit and log battery percentage via BLE
    - Read analog pin to calculate battery percentage in ESP32 firmware
    - Include battery level in the SYNC packet payload
    - Update Python parser to extract and display battery statistics
2026-05-10 updated battery status readings
2026-05-10 feat: add battery metrics to data pipeline and dashboard
    - Interpolate battery percentage across IMU samples
    - Include battery level in STFT windows
    - Display start/end battery levels on the Streamlit dashboard
    - Remove demo data generation script
    - Update README.md to reflect new battery tracking and dashboard data ingestion features
2026-05-10 fix: handle android lightblue formats and truncated ble packets
    - Fix datetime parsing in `lightblue_parse.py` to support Android exports containing GMT offsets.
    - Modify DATA packet parser to handle truncated BLE payloads (extracting as many full samples as possible).
    - Bypass the 25Hz low-pass Butterworth filter in `analysis.py` and `dashboard.py` if the sampling rate drops below the Nyquist requirement.
2026-05-10 added stl_files
    [box-3.stl]
2026-05-28 fix: correct TinyGPS speed method to kmph()
    [bikesensor.ino]
2026-05-28 fix: add charsProcessed to diagnostics
    [bikesensor.ino]
2026-05-28 feat: add battery level interpolation and dashboard metrics card
2026-05-29 fix: robust filesystem synchronization and live battery logging
    [bikesensor.ino]
2026-05-29 feat: add X-Axis toggle between Distance and Elapsed Time in Analytics tab
2026-05-29 fix zero-byte directory entry bug on battery power cycle
    [bikesensor.ino]
2026-05-29 add non-blocking heartbeat LED blink and remove all remote notifications for security and privacy
2026-05-29 fix: race-free gps latch, timing jitter, robust fallback and upload timeout
    [bikesensor.ino]
2026-05-29 fix: safely handle NaN battery percent values in Streamlit metric
2026-06-10 feat: add custom pcb layout, production gerbers, and updated readme
    [bikesensor_pcb-B_Cu.gbr, bikesensor_pcb-B_Mask.gbr, bikesensor_pcb-B_Silkscreen.gbr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]
2026-07-28 Harden offline upload flow and configurable server endpoint
    - make firmware upload endpoint configurable via SERVER_HOST/PORT/PATH\n- switch offline processing to FastAPI BackgroundTasks\n- add /health endpoint for API+DB liveness\n- validate X-Ride-Filename to prevent path traversal\n- update docs for mDNS endpoint and production startup\n- add tests for filename validation and health endpoint\n\nCo-authored-by: Copilot <223556219+Copilot@users.noreply.github.com>
    [bikesensor.ino]
2026-07-28 Improve curb event detection and dashboard robustness
    - add event-based curb detection with peak/prominence/refractory logic
    - switch dashboard curb markers to deduplicated events
    - align high-frequency label with computed 30-120 Hz band
    - harden multi-ride loading against missing/corrupt ride files
    - add analysis tests for curb event behavior and high-band consistency
2026-09-16 Stop losing ride data, and document the unverifiable pin mapping
    Three data-loss paths, all of which could destroy rides that cost a real
    bike trip to reproduce:
    - The background DSP task deleted raw_imu.csv on any exception. Since the
    firmware wipes the SD card as soon as it sees HTTP 200, and the server
    acks before processing starts, any downstream bug erased the ride from
    both places at once. Failures now keep the bytes and leave a marker.
    - ride_id used second resolution while the firmware uploads every pending
    file back-to-back with no delay, so two rides in the same second meant
    the second overwrote the first. Ids now carry a content hash, which also
    makes a re-upload of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
2026-09-16 Point the firmware at kiel.earth over TLS, and sample at 200 Hz
    Upload path:
    - HTTPS via WiFiClientSecure with the Mozilla root bundle the Arduino core
    ships. Pinning a leaf certificate would break every 90 days when it
    rotates. One attempt per file per sync, because WiFiClientSecure is
    documented to leak memory when verification fails and a retry loop on a
    broken handshake would bleed heap.
    - Authorization: Bearer DEVICE_TOKEN, separate from ADMIN_PASSWORD - this
    token is compiled into a board that rides around on a bicycle and has to
    be revocable without locking anyone out of admin.
    - Files are deleted from the SD card only on an explicit 2xx. The server
    stores the raw bytes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
    [bikesensor.ino]
2026-09-16 Make the diagnostic find peripherals instead of assuming the pin map
    The board has no signal names on the silkscreen and no ESP32 pin names in
    the schematic, so the pin mapping is the thing most likely to be wrong on
    an assembly - and the old sketch could only confirm or deny the mapping it
    already assumed.
    It now probes each GPIO's pull-up/pull-down behaviour to see what is
    physically attached, confirms the MPU-6050 by reading WHO_AM_I rather than
    by taking an I2C ACK at face value, and tries the GPS at both pin orderings
    and two baud rates. It loops so the output can be captured at any time.
    Two findings recorded as comments because they cost real debugging time:
    - An ACK proves nothing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
    [diagnostic.ino]
2026-09-16 Add a software short test that needs no multimeter
    Drive each pin high, then low, and read the pad back. The ESP32-C3 sources
    about 40mA, so a real short to ground wins that contest and the pin cannot
    be driven high. That is a continuity test with no instrument attached.
    This turned out to matter more than expected. The passive pull-up test
    flagged GPIO 0, 4, 5 and 6 as "held low", which looked like four faults.
    Driving them shows only GPIO 5 and 6 are actually shorted - 0 and 4 drive
    fine and were merely pulled down weakly, GPIO0 by the 100k battery divider
    leg doing exactly its job. A passive test cannot tell a short from a
    resistor; this one can.
    On the board in hand it localised the fa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
    [diagnostic.ino]
2026-09-16 Distinguish a bus state from a genuine short before calling it a fault
    The short test flagged GPIO5 (MISO) and GPIO6 (SDA) as shorted to ground.
    Two independent solder faults landing on precisely the two pins that have
    an active device attached was too much of a coincidence, and there is an
    ordinary explanation for each:
    - a selected SD card actively drives MISO, and
    - an MPU left mid-transaction holds SDA low through its open-drain output
    until it receives enough clocks to finish, which beats the ESP32 driving
    high and looks identical to a short.
    So the sketch now deasserts CS and clocks the SPI bus before judging MISO,
    and performs standard I2C recovery - up to 16 SCL pulses followed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
    [diagnostic.ino]
2026-09-17 Shrink the carrier board to the real module footprints
    Re-lays the board out against the actual ESP32-C3 SuperMini and Wemos
    battery shield dimensions: ESP32 rows J1-J2 go 800 -> 600 mil, shield
    rows J6-J7 go 1000 -> 900 mil, and the outline drops from 72.75 x 167.43
    to 38.74 x 114.47 mm -- the size the README already claimed. Mounting
    holes H1-H4 are dropped along with the reclaimed area.
    KiCad is not installed on this machine, so this was verified by
    rebuilding the connectivity graph straight from the file: every pad sits
    at least 1.16 mm inside the board edge, and every net is fully routed
    except +3V3, whose track stops 1.48 mm short of C1 pin 1. That bulk cap
    is still floating and needs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
    [bikesensor_pcb.kicad_pcb, bikesensor_pcb.kicad_sch]
2026-09-17 Swap the bus-recovery diagnostic for an SD mount check
    The GPIO6 short is cleared, so the lockup-vs-short discrimination test
    has served its purpose; it stays in history at 1953733 if it is ever
    needed again. This one walks the card up through 400 kHz, 1 MHz and
    4 MHz, because cheap modules on hand-wiring frequently will not mount
    at full clock.
    Claude-Session: https://claude.ai/code/session_01EcNmG8boCU9EBpJGftDikR
    [diagnostic.ino]
2026-09-17 Put signal names on the silkscreen
    The board had no text on it at all beyond the reference designators, so
    assembling or probing it meant counting header pins against a table in
    the README. Adds 42 F.SilkS labels generated from the routed netlist: a
    short name beside every connected pin on J1-J5, VBAT, the J7 switch
    feed, and module names.
    Names are abbreviated to fit the 2.54 mm pitch (GTX/GRX for the GPS
    UART, DTX/DRX for the debug UART, ADC for the battery divider) at 0.8 mm
    height, which is the usual fab minimum. Placement was checked
    programmatically: no label overlaps a pad, none collide with each other,
    and all sit inside the board outline. Worth an eyeball in KiCad anyway.
    Co-Autho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
    [bikesensor_pcb.kicad_pcb]
2026-09-17 Make the docs describe the system that actually exists
    README and CLAUDE.md both still described the Raspberry Pi as the upload
    target, 100 Hz sampling, and a coordinate fallback that was removed. The
    firmware has posted to kiel.earth over TLS at 200 Hz since 9af4828, and
    process_unified_offline raises rather than inventing a location.
    Also:
    - Section 5 documented the macOS SSH notification hook, which was deleted
    from the server for privacy in 3e252cc / a728063. It is now marked
    removed rather than describing a feature that is gone, and no longer
    publishes a personal machine hostname or the home LAN IP -- this repo
    is public.
    - Section 7.3 pointed at data/pending/ (the code writes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
2026-09-17 Remove duplicated and stale files from the repo
    - The nine loose *.gbr/*.drl at custom_pcb/bikesensor_pcb/ were a
    byte-identical duplicate of production/, plotted one minute earlier.
    Both described the old oversized board; production/ is kept as the
    single location and will be re-plotted after the outstanding KiCad
    fixes.
    - The four assets/Screenshot 2026-06-15 files were referenced by nothing
    and had gone stale -- they still showed mounting holes H1-H4, which the
    re-layout removed. Recoverable from 3ed6f84; fresh exports will be
    wired into the README.
    - .kicad_prl is KiCad UI state and .gitignore already listed it, but it
    had been tracked since before that rule, so gitignore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
    [bikesensor_pcb-B_Cu.gbr, bikesensor_pcb-B_Mask.gbr, bikesensor_pcb-B_Silkscreen.gbr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]
2026-09-17 Add the CS pull-up and close the two open nets
    R3 (10k, /SPI_CS to +3V3) is in the design, and +3V3 now reaches C1
    pin 1. Verified from the file rather than from DRC's word for it:
    0 unrouted nets across the whole board, and R3's pads land on +3V3
    and /SPI_CS.
    Also re-aligns the J4 MOSI and SCK silkscreen labels. They had drifted
    3.46 mm and 2.92 mm down while the silk overlaps were being cleared,
    which put MOSI beside the SCK pin and SCK beside the CS pin -- wiring
    the SD card from those labels would have swapped the SPI lines. All six
    J4 labels now sit exactly on their pads.
    Claude-Session: https://claude.ai/code/session_01EcNmG8boCU9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
    [bikesensor_pcb.kicad_pcb, bikesensor_pcb.kicad_sch]
2026-09-17 Re-plot the board and document it in the README
    The gerbers in production/ were re-plotted from the current design and
    bikesensor.zip rebuilt from them -- it still held the 2 June files, so
    uploading it to a fab would have produced the old 167 mm board. The new
    archive is verified to contain the 38.74 x 114.47 mm outline and no
    __MACOSX resource-fork entries, which some fabs reject.
    Adds the schematic and a 3D render to the README hardware section, and
    corrects the status block and PIN_VERIFICATION.md: both pre-fabrication
    blockers (the unrouted +3V3 to C1, and the missing CS pull-up) are now
    closed. H3, H5 and most of H4 remain open as cautions, and the board is
    still unfabricated and unve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
    [bikesensor_pcb-B_Cu.gbr, bikesensor_pcb-B_Mask.gbr, bikesensor_pcb-B_Silkscreen.gbr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]
2026-09-17 Add a bill of materials to the hardware notes
    Derived from the footprints in the board file rather than from memory,
    so the quantities and pitches match what is actually on the PCB. Records
    the two constraints that are easy to get wrong when ordering: SW1 is a
    2.0 mm pitch C&K part that a generic 2.54 mm slide switch will not fit,
    and the GPS module must have 3.3 V logic because it is fed from 5 V with
    no level shifting.
    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
2026-09-22 Upload rides under their new filenames
    The Wi-Fi sync only collected files named ride_*.csv. Since rides started
    being named after the satellite clock (r<date>_<time>.csv, or rboot_<hex>.csv
    before a fix), nothing matched, so no ride was ever uploaded. The sync now
    takes any .csv file starting with "r", which also covers the old ride_ names,
    and skips directories.
    Claude-Session: https://claude.ai/code/session_01GieErQSjQVauJvLyxdeStZ
    [bikesensor.ino]
2026-09-22 Remove the Raspberry Pi backend
    The ESP32 uploads straight to kiel.earth, which stores, processes and
    maps the rides from its own repository. The FastAPI server, Streamlit
    dashboard, Python DSP and their tests in src/ and tests/ were no longer
    used by anything, so they go, along with the uv project files.
    README and CLAUDE.md now describe the firmware -> kiel.earth upload
    contract instead of the Pi setup. The old code is recoverable from
    f155d5b.
    Claude-Session: https://claude.ai/code/session_01AQWnD2B1yaDWvQzygXEwsU
2026-09-22 Fix stale sample-rate and PCB notes
    The firmware samples at 200 Hz, but the README diagram and a loop comment
    still said 100 Hz. CLAUDE.md still called production/ stale and listed
    two PCB issues that PIN_VERIFICATION.md records as fixed on 2026-09-17.
    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
    [bikesensor.ino]
2026-09-22 Map the firmware to the pins the carrier board actually routes
    Checked J1/J2 in the routed netlist against the real ESP32-C3 SuperMini
    pinout (5V GND 3V3 IO4..IO0 on one row, IO5..IO10 IO20 IO21 on the other,
    both counted from the USB end). The board was laid out against a pinout
    that does not exist: with the module's 5V pin in J1.1, not one signal
    reaches the GPIO the firmware used. The hand-wired prototype followed the
    firmware, which is why it worked.
    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
2026-09-22 Record that the ordered SuperMini has the expected pin order
    Claude-Session: https://claude.ai/code/session_019WeuGKHPdKzEKmTnuq4Hqo
2026-09-28 Say the SuperMini only fits the carrier face down and add assembly notes
    Claude-Session: https://claude.ai/code/session_013sitSS9eygch8zBr7bZaQ1
2026-09-28 Present face-down mounting as the standard assembly for this board
    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
2026-09-28 Record rides on motion, switch Wi-Fi off after syncing and stop repeating stale GPS positions
    Rides now start after a few seconds of motion and end after three still
    minutes, followed by an upload attempt. Wi-Fi is fully off outside a sync.
    A missing SD card or IMU is retried instead of hanging, failed IMU reads
    no longer write garbage, and the file is flushed rather than closed and
    reopened every 5 s.
    Claude-Session: https://claude.ai/code/session_01JW3JrhWABzoKPGiyT43Has
    [bikesensor.ino]
2026-09-28 Print no battery on the console instead of -1%
    The CSV already leaves battery_pct empty when the reading is not a plausible
    cell; only the diagnostic line printed the -1 sentinel.
    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
